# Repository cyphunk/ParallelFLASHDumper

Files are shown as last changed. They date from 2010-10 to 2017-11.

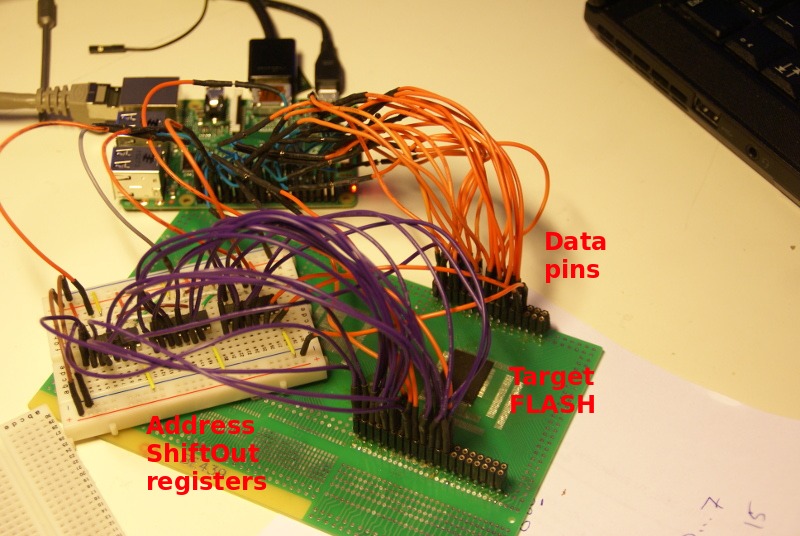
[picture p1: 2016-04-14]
ParallelFLASHDumper_rpi.jpg

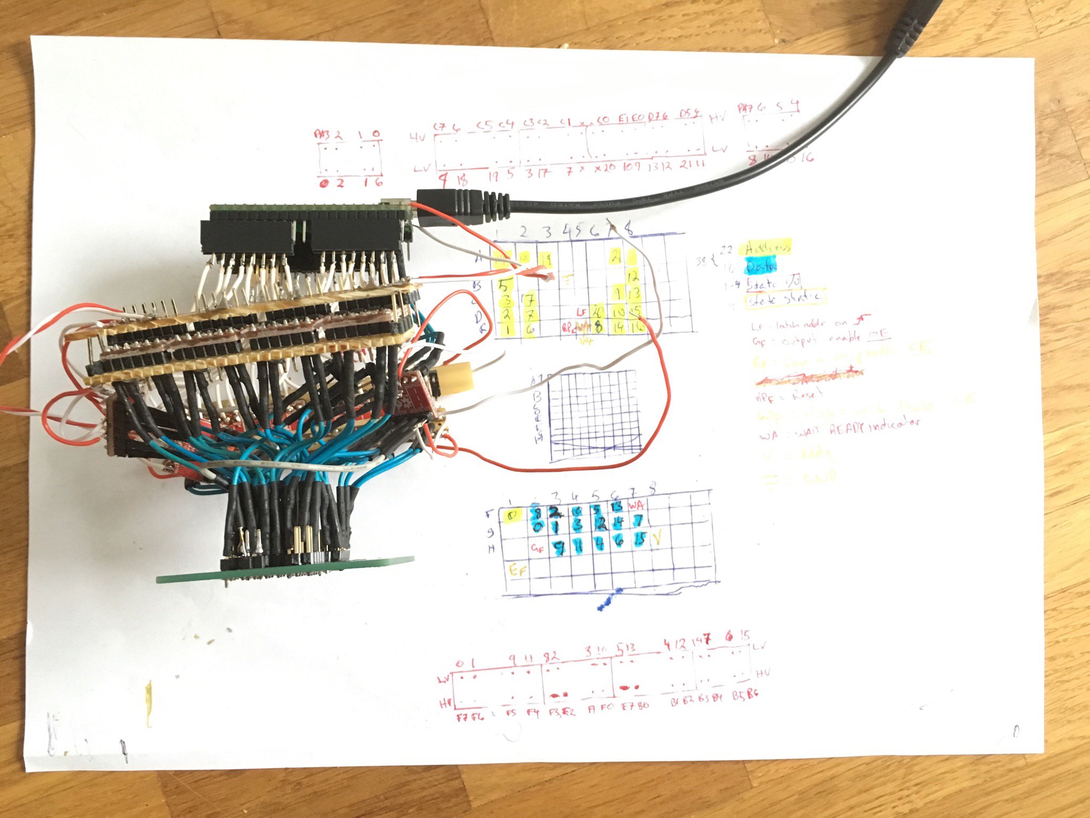
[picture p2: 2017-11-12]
_/ParallelFLASHDumper_M36W0R604/ParallelFLASHDumper_M36W0R604.jpg

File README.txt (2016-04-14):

 Parallel FLASH Dumper (v0.2.2 20160414)
 There are many commercial FLASH memory programmers but their out of box 
 support for different FLASH chips can be a problem, or I should say 
 some FLASH chips just are not supported.  The meaning of "Parallel" in
 this context means we will be connecting directly to the full address 
 and databus of the target using shift in and out registers.  At the 
 moment only read (hence dump) functionality is supported.   

 Further documentation: http://deadhacker.com/tools/

 SETUP:
 First, the timing of when to throw Chip Select, Write Select or other
 lines might differ from your chip.  You can try the default here but
 you will likely need to modify.  For this you need to consult the 
 timing diagrams of your target.  Assuming that is correct...
 
 1. Connect "parallel out" shift registers to address pins of target 
 2. Connect "parallel out" pins to arduino:
      ADDR_STROBE   = 8;  // latch orange (color shown in fz)
      ADDR_DATAOUT  = 7;  // green
      ADDR_CLOCK    = 6;  // yellow
 3. Connect "parallel in" shift registers to data out pins of target
 4. Connect "parallel in" pins to arduino:
      IN_STROBE     = 4; // latch orange
      IN_DATAIN     = 3; // green
      IN_CLOCK      = 2; // yellow  
 5. Define MAX_ADDR. Code with dump address 0 to MAX_ADDR

 USAGE: 
 1. Load code to microcontroller, code will start dumping raw
    data within a second or two.
 2. Open serial terminal with baud rate 230400. Data will be 
    dumped in raw binary form over serial and might take a 
    couple hours. 
    Example dump from console (unix/linux):
      stty -f /dev/tty.usb* 230400; cat /dev/cu.usb* > dump
    This will dump raw data to dump
    To monitor progres open in tail through a hex editor:
      tail -f dump | xxd
    You can also put some LED's on the address lines for visual
    status.
  
 AUTHORS & CODE BRANCHES:
 cyphunk  http://github.com/cyphunk/ParallelFLASHDumper
 gina hortenbach contributed the raspberry pi version
 
 DEVELOPER NOTES:
 In the future with write support SFI could be used.  U-boot can 
 be used as a reference to help. I would advocate using SFI when 
 it is supported but in some cases there is no serial interface 
 available for this and will require setting up a parallel 
 conenction anyway.  The advantage of using this software is that
 only the read logic is required when all you care to do is dump
 the flash. That and, its cheap.
 I tried to speed things up by using a SD card but this turned out
 to be slower than serial actually.  Perhaps there are ways to
 improve such a setup though.
 About serial throughput issues on Arduino:
 http://www.arduino.cc/cgi-bin/yabb2/YaBB.pl?num=1281611592/0

 TROUBLESHOOTING:
 Various issues and solutions I've run into
  
 * check data lines to determine proper byte order
 * check address lines to determine proper bit order (MSB or LSB).
   leds can help
 * check solder connection to pins.  Sometimes a multimeter check 
   is enough to press the pin to its pad while checking continuity.
   Hence, you might think it is connected with a continuity test 
   when it isnt.  In such cases you will only get a hint of this 
   when scrutinizing the address in the dump, to see where data 
   out might duplicate. (where address bits aren't registering)

 TROUBLESHOTTING EXAMPLES:
 a log of human error from various projects
 
 * Vss, CE#, OE# of chip were shorted at pin N of dual (word) 
   shift reg. I was able to find this because target dump had
   a section of memory with all FFFF's that were being read 
   as 7FFF due to the grounded pin N.  This happened because 
   I got my orientation of the shift regs upside down.
 * The target chip itself was plugged up wrong due to mixing up
   the orientation with address being connected to data and 
   data to address.  The result was some odd behavior and output
   that looked too constant.
 * Address pin 1 of target was not properly soldered to the shift
   reg input.  This resulted in the board seeing address 00001101
   when I/microcontroller was sending 00001111. I was able to 
   notice this because every 4 bytes repeated once in the dump.
 * The bit order of the ShiftOut for the address shiftregs was 
   LSB when it should have been MSB. I only noticed this after 
   plugging up LED's to each addr lineon the hunch that this 
   might be an issue.

 This code is public domain, [ab]use as you wish and at your own risk

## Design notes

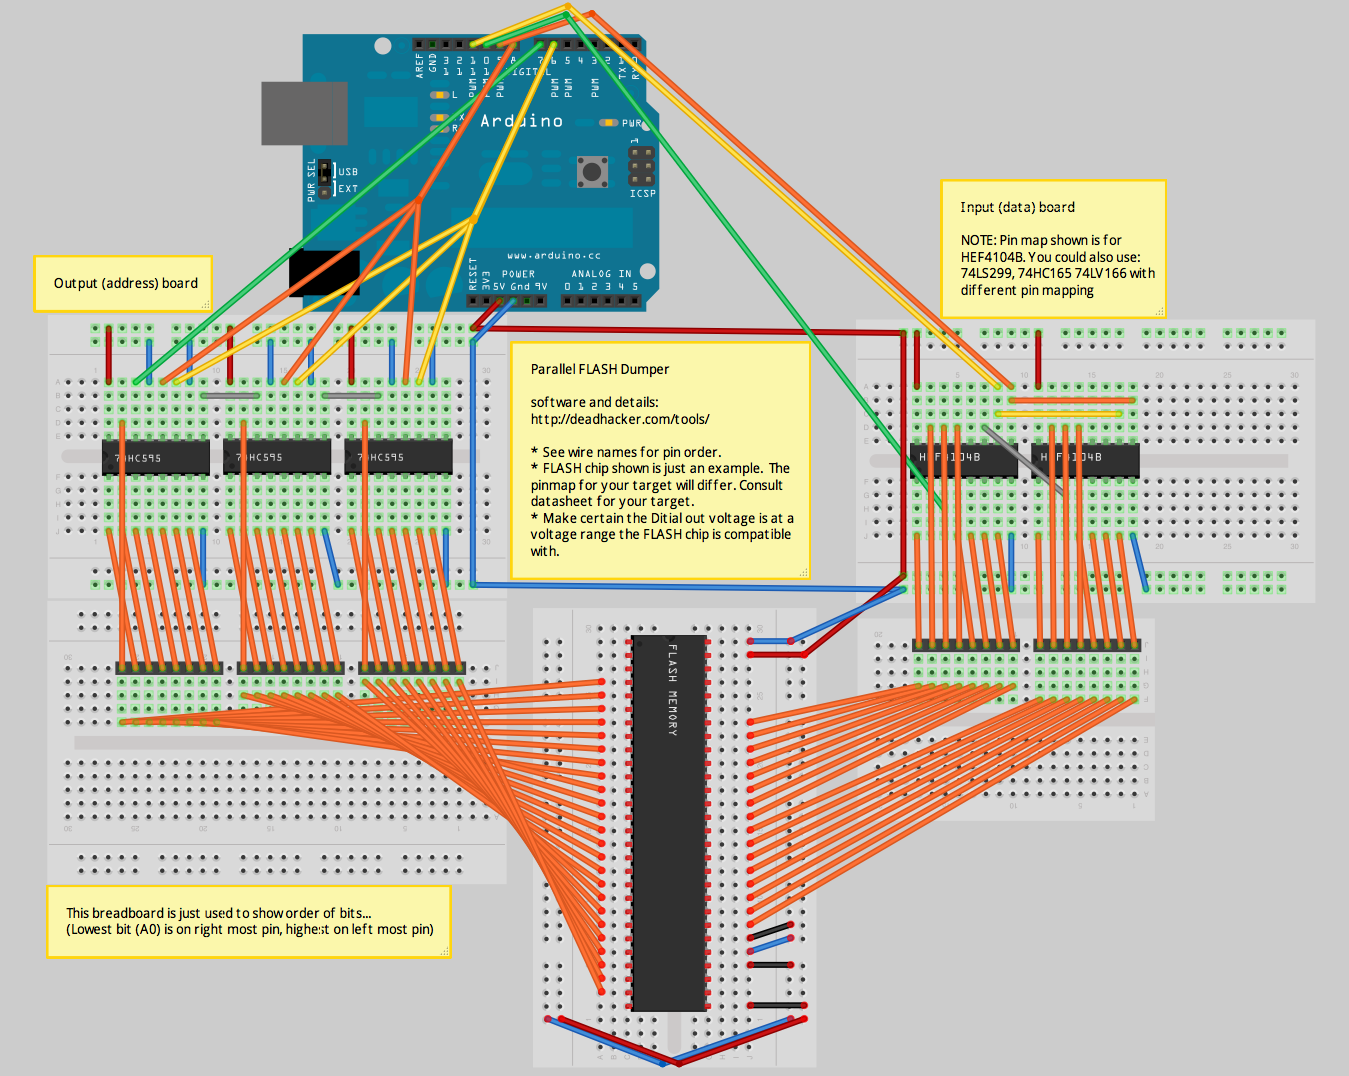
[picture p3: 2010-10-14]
ParallelFLASHDumper.fzz.png

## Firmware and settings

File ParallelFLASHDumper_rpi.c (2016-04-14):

#include <stdio.h>
#include <wiringPi.h>

/* Written by Gina Hortenbach */

/*
   This code is intended to run on the Raspberry Pi with the WiriPi Library.
   It has the advantage over the Arduino version in that less shift registers
   are required and dumping is significantly faster.

   WiriPi can cause troubles. If you run into trouble check you have version:

     wiringPi-78b5c32

   The code is currently configured for a dump setup that uses ShiftOut
   registers for address lines and Rapsberry Pi GPIO pins for input data.
   See ParallelFLASHDumper_rpi.jpg

   Compile:

   cc -o ParallelFLASHDumper_rpi ParallelFLASHDumper_rpi.c -lwiringPi -lpthread

*/

/*
 * BEGIN USER DEFINITIONS
 */
#define ADDR_STROBE      25  // latch orange
#define ADDR_DATAOUT     29  // green
#define ADDR_CLOCK       28  // yellow
#define ADDR_A24         26

// define according to the size of your target chip
#define MAX_ADDR    0xFFFFFFFF


// INPUT DATA pins
#define IN_DQ00        9 //
#define IN_DQ01        7 //
#define IN_DQ02        1 //
#define IN_DQ03        2 //
#define IN_DQ04        3 //
#define IN_DQ05        5 //
#define IN_DQ06        6 //
#define IN_DQ07       14 //
//#define IN_DQ08       15 //
#define IN_DQ08       31 //
#define IN_DQ09       16 //
#define IN_DQ10        0 //
#define IN_DQ11        4 //
#define IN_DQ12       12 //
#define IN_DQ13       13 //
#define IN_DQ14       10 //
#define IN_DQ15       11 //

//#define CE              // gnd
#define OE             8 //
#define BYTE          21
#define WP            22
#define RST           23
#define WE            27
#define RYBY          24


/*
 * END USER DEFINITIONS
 */

 unsigned char input1 = 0;
 unsigned char input2 = 0;
 unsigned char input[2];


// assuming LSB shifted out first
void shiftOut(int myDataPin, int myClockPin, char byte) {
        int i; // cant use unsigned or byte otherwise loop never ends

        pinMode(myClockPin, OUTPUT);
        pinMode(myDataPin, OUTPUT);

        char currentbit;
          for (i=0; i<=7; i++) {
            // byte 0b11001011
            currentbit = (byte       & (1 << i           ))            >>   i;
            // i=0       (0b11001011 & (1 << 0=0b00000001))=0b00000001 >>   0  =  1
            // i=1       (0b11001011 & (1 << 1=0b00000010))=0b00000010 >>   1  =  1
            // i=2       (0b11001011 & (1 << 2=0b00000100))=0b00000000 >>   2  =  0
            // i=3       (0b11001011 & (1 << 3=0b00001000))=0b00001000 >>   3  =  1
            digitalWrite(myClockPin, 0);
            delayMicroseconds(2);

            digitalWrite(myDataPin, currentbit);

            digitalWrite(myClockPin, 1);
            delayMicroseconds(2);
          }
}


void sendDataOut(unsigned long value) {
  digitalWrite(ADDR_STROBE, LOW);

  unsigned char byte1 =  value &   0x0000FF;
  unsigned char byte2 = (value &   0x00FF00) >> 8;
  unsigned char byte3 = (value &   0xFF0000) >> 16;
  unsigned char a24   = (value & 0x01000000) >> 24;

  // shift out assumes LSB first
  shiftOut(ADDR_DATAOUT, ADDR_CLOCK, byte1 ); //first byte
  shiftOut(ADDR_DATAOUT, ADDR_CLOCK, byte2  ); //second byte
  shiftOut(ADDR_DATAOUT, ADDR_CLOCK, byte3 ); //third byte
  digitalWrite(ADDR_A24, a24);

  // LATCH/STROBE:
  digitalWrite(ADDR_STROBE, HIGH);
  delayMicroseconds(2);
  digitalWrite(ADDR_STROBE, LOW);
}


int main(int argc, char const *argv[]) {
  FILE* file;
  if (argc != 2) {
    printf("provide dump file as argument\n");
    return 1;
  }

  file = fopen(argv[1], "wb");

  //chech if wiringPi build in successfully
  if (wiringPiSetup () == -1)
    return 1 ;

    pinMode(OE, OUTPUT);
    pinMode(WE, OUTPUT);
    pinMode(WP, OUTPUT);
    pinMode(BYTE, OUTPUT);
    pinMode(RST, OUTPUT);
    pinMode(RYBY, INPUT);
    //digitalWrite(CE, LOW); // grounded
    digitalWrite(OE, LOW);
    digitalWrite(WE, HIGH); // Not care?
    digitalWrite(WP, LOW); // Not care?
    digitalWrite(BYTE, HIGH); // LOW 8bit mode HIGH 16 bit mode
    digitalWrite(RST, HIGH); //

    pinMode(ADDR_STROBE, OUTPUT);
    pinMode(ADDR_DATAOUT, OUTPUT);
    pinMode(ADDR_CLOCK, OUTPUT);
    pinMode(ADDR_A24, OUTPUT);
    pinMode(IN_DQ00, INPUT);
    pinMode(IN_DQ01, INPUT);
    pinMode(IN_DQ02, INPUT);
    pinMode(IN_DQ03, INPUT);
    pinMode(IN_DQ04, INPUT);
    pinMode(IN_DQ05, INPUT);
    pinMode(IN_DQ06, INPUT);
    pinMode(IN_DQ07, INPUT);
    pinMode(IN_DQ08, INPUT);
    pinMode(IN_DQ09, INPUT);
    pinMode(IN_DQ10, INPUT);
    pinMode(IN_DQ11, INPUT);
    pinMode(IN_DQ12, INPUT);
    pinMode(IN_DQ13, INPUT);
    pinMode(IN_DQ14, INPUT);
    pinMode(IN_DQ15, INPUT);

  //
  // OUTPUT (address)
  //
  pinMode(ADDR_STROBE, OUTPUT);
  pinMode(ADDR_CLOCK,  OUTPUT);
  pinMode(ADDR_DATAOUT, OUTPUT);

  //unsigned long addr = 0xFFFFF0; // debug
  unsigned long addr = 0x000000;

  while (addr < MAX_ADDR) {
      delayMicroseconds(4);
      //
      // SEND OUTPUT (address)
      //
      sendDataOut(addr);
      //addr += 0x1000; // debug
      addr += 1;
      //
      // READ INPUT (data)
      //

      input1 = 0;
      input2 = 0;
      input1 = digitalRead(IN_DQ00);
      input1 = input1 | (digitalRead(IN_DQ01) << 1);
      input1 = input1 | (digitalRead(IN_DQ02) << 2);
      input1 = input1 | (digitalRead(IN_DQ03) << 3);
      input1 = input1 | (digitalRead(IN_DQ04) << 4);
      input1 = input1 | (digitalRead(IN_DQ05) << 5);
      input1 = input1 | (digitalRead(IN_DQ06) << 6);
      input1 = input1 | (digitalRead(IN_DQ07) << 7);
      input2 = digitalRead(IN_DQ08);
      input2 = input2 | (digitalRead(IN_DQ09) << 1);
      input2 = input2 | (digitalRead(IN_DQ10) << 2);
      input2 = input2 | (digitalRead(IN_DQ11) << 3);
      input2 = input2 | (digitalRead(IN_DQ12) << 4);
      input2 = input2 | (digitalRead(IN_DQ13) << 5);
      input2 = input2 | (digitalRead(IN_DQ14) << 6);
      input2 = input2 | (digitalRead(IN_DQ15) << 7);


      //
      // SAVE/PRINT DATA OUT
      //
      // Reverse the order if needbe:
      //printf("%c", input1);
      //printf("%c", input2);
      if (fputc(input1, file) == EOF || fputc(input2, file) == EOF) {
         printf("error at addr 0x%x\n", addr);
	 return 1;
      }


  }
  return 0;

}

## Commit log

2010-10-14 initial release
    [ParallelFLASHDumper.fz]
2013-03-19 update for Arduino >1, Fritzing 2013
    [ParallelFLASHDumper.fz, ParallelFLASHDumper.fzz]
2016-04-14 Raspberry Pi version added
2017-11-12 arduino version that uses no shift registers
    all data,state,address pins of target chip connected directly
    to microcontroller. testing on the ST M36W0R604 NOR FLASH
    chip with a Teensy++2.0
